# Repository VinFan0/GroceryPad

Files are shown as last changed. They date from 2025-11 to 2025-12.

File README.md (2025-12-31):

# GroceryPad
## Overview

GroceryPad is a compact display for shopping lists, to-do lists, reminders, and more. The on-board ESP32 microcontroller acts as a display driver, as well as hosts an HTTP server on the local network. Data sent to the server in the form of an HTTP POST is parsed and sent to the 3.7" Epaper module.

GroceryPad is initially designed to sync with a list managed in the Reminders app of an iOS device. In this configuration, the iOS device sends a scheduled HTTP POST with the contents of the reminder/list to the server hosted by the GroceryPad device. 

**R1.1-A changes**
- Power switch
- Android companion app for checklist display

### Hardware Requirements
- [ESP32-C3 Supermini microcontroller](https://www.espboards.dev/esp32/esp32-c3-super-mini/)
- [WeAct 3.7" Epaper module](https://github.com/WeActStudio/WeActStudio.EpaperModule)
- [HiLetgo TP4056 USB-C Lithium Battery Charging Module](https://www.amazon.com/HiLetgo-Lithium-Charging-Protection-Functions/dp/B07PKND8KG)
- [3.7V Rechargeable Lithium Polymer battery](https://www.amazon.com/dp/B0CNLPK1F8?ref=ppx_yo2ov_dt_b_fed_asin_title&th=1)
- 3mm indicator LED
- Smartphone (for automatic list syncing)

### Software Requirements
Code is uploaded to the board via ArduinoIDE, which can be downloaded here: [Download ArduinoIDE](https://www.arduino.cc/en/software/)

To connect with the ESP32 board, you must also install the ESP32 board. Instructions are available on the [espressif website](https://docs.espressif.com/projects/arduino-esp32/en/latest/installing.html)

For the automatic syncing with a smartphone list, an additional app must be used to schedule the sending of the HTTP POST. iPhones can use the Shortcuts app, which is installed by default on all devices running iOS 13 or later. For Android, I recommend [Tasker](https://play.google.com/store/apps/details?id=net.dinglisch.android.taskerm&hl=en_US). Steps for setting this up are found under the **Setup** section.

## Setup
For the GroceryPad device to function, a connection to a local WiFi network is required. Included with the Arduino sketch is a `ssid_options.h` file. This header file can be used to define the SSID and password variables the ESP32 will use to connect to WiFi. Fill in the `ssid` and `password` strings with your local WiFi details. *Note: The ESP32 is only compatible with 2.4 GHz WiFi.*

Once the `ssid_options.h` file is filled in, the code can be compiled and loaded onto the microcontroller. If the connection is successfull, the microcontroller will print a "WiFi Connected" message to the console. Along with the success message, the IP address will also be printed. Take note of this IP address, as it will be required in sending the HTTP POST messages.

### iOS Shortcuts Configuration
Setting up the Shortcut to periodically send the HTTP POST is not complicated, but can take some time to figure out if you are new to workflow automations or Apple Shortcuts specifically. Here is provided a simple walkthrough of setting up the Shortcut.

Items necessary to creating the Shortcut:
- Apple Shortcuts app is installed
- The IP address of the ESP32 HTTP server
- A Reminder list on the same iOS device

**Step 1**

**Sending messages manually** with curl

Messages can also be sent to the device manually using a linux-style terminal and the `curl` command. Basic syntax is

`curl -X POST http://<ESP IP ADDRESS>/reminder -H "Content-Type: application/json" -d '<MESSAGE CONTENT>'`

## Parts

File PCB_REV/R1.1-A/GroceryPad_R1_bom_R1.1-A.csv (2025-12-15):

Component | Description | Part | References | Value | Footprint | Quantity Per PCB | Datasheet | MFR | MPN | SPR | SPN
1 | 8 Pin Wire to Board Connector | e-ink_Display | C1 | ~ | 1.25mm_8P_WireToBoard | 1 | kicad-embed://JUSHUO_C29041.pdf | JUSHUO | 1.25T-8PWT | JLCPCB | C29041
2 | Light emitting diode | LED | D1 | LED | LED_D3.0mm_Horizontal_O6.35mm_Z2.0mm | 1 | ~ | Lumimax Optoelectronic Technology | LEDDC-3BLU | Digikey | 4491-LEDDC-3BLU-ND
3 | Resistor, US symbol | R_US | R1 | 2k | R_0805_2012Metric | 1 | kicad-embed://JLC_C1359.pdf | UNI-ROYAL(Uniroyal Elec) | 0805W8J0202T5E | JLCPCB | C1359
Component Groups: | 3
Component Count: | 3
Fitted Components: | 3
Number of PCBs: | 1
Total components: | 3
Schematic Version: | R1.1-A
Schematic Date: | 11/26/25
PCB Variant: | default
BoM Date: | 2025-12-13T23:08:35-0700
Schematic Source: | GroceryPad_R1.1-A.kicad_sch
KiCad Version: | Eeschema 9.0.6

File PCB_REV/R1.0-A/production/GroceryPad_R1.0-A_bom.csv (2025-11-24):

Designator | Footprint | Quantity | Value | LCSC Part #
R1 | R_Axial_DIN0207_L6.3mm_D2.5mm_P7.62mm_Horizontal | 1 | 2k | 0805W8J0202T5E

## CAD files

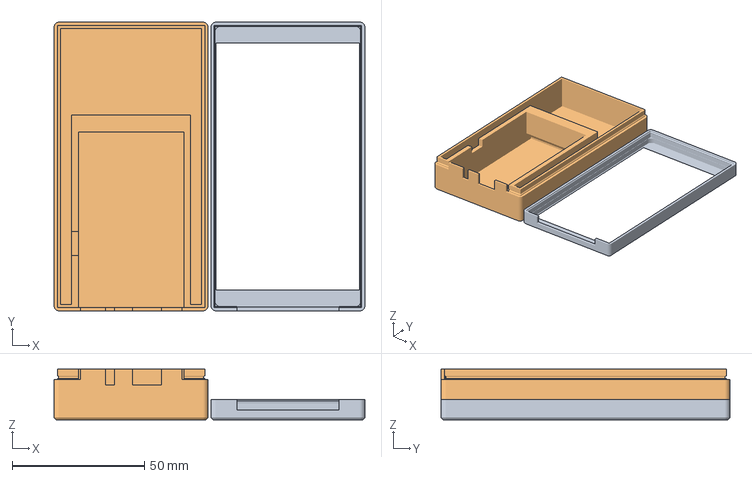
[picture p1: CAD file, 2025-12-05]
PCB_REV/R1.0-A/printing/GroceryPad.3mf
117.8 x 109.4 x 19.2 mm
Front Plate_R1.0-C.stl
Back Cover_V4.stl

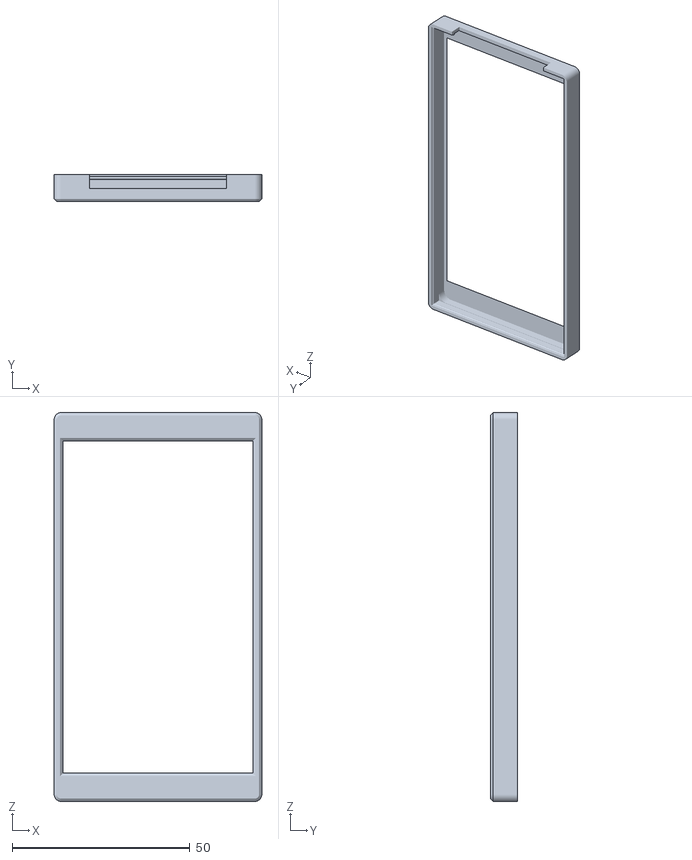
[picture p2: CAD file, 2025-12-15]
PCB_REV/R1.0-A/printing/STL/Front Plate_V4.stl
58.4 x 7.70 x 109.4

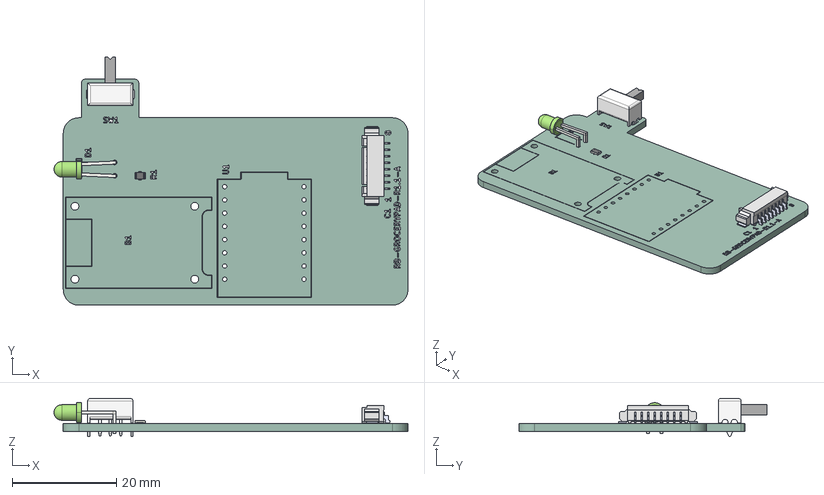
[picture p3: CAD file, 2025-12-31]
PCB_REV/R1.1-A/GroceryPad_R1.1-A.step
68.0 x 47.7 x 7.30 mm
10114830-xxxxxLF (Additional)_10114830-10108LF
LED_D3.0mm_Horizontal_O6.35mm_Z2.0mm
SK12D07VG5 Slide Switch SPDT
R_0805_2012Metric
GroceryPad_R1.1-A_silkscreen
GroceryPad_R1.1-A_PCB

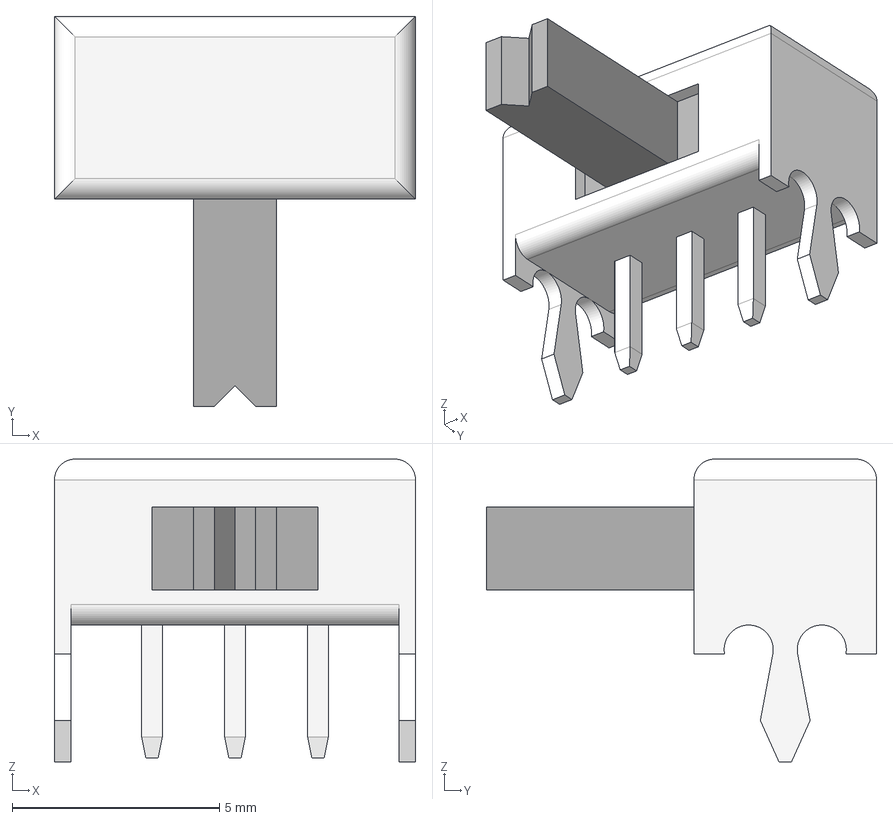
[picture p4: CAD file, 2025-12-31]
PCB_REV/R1.1-A/models/SK12D07VG5 Slide Switch SPDT.step
8.70 x 9.40 x 7.30 mm

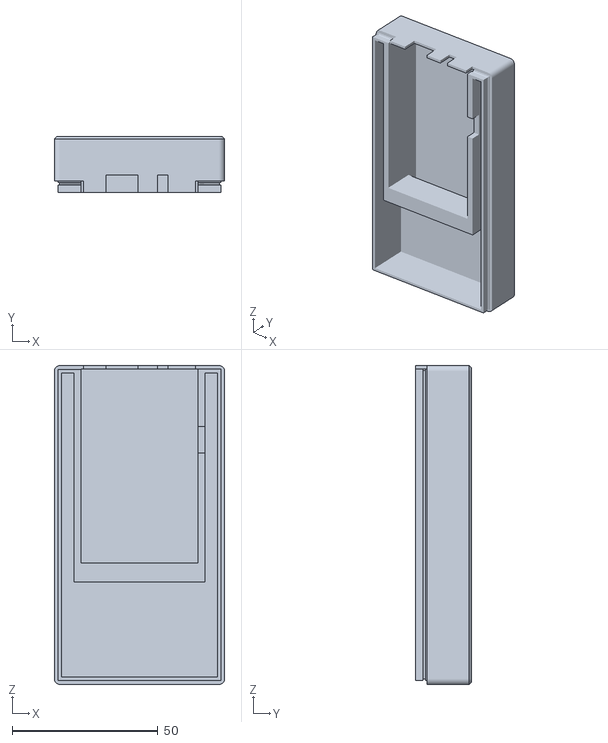
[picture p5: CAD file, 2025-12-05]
PCB_REV/R1.1-A/printing/STL/Back Cover_V4.stl
58.4 x 19.2 x 109.4

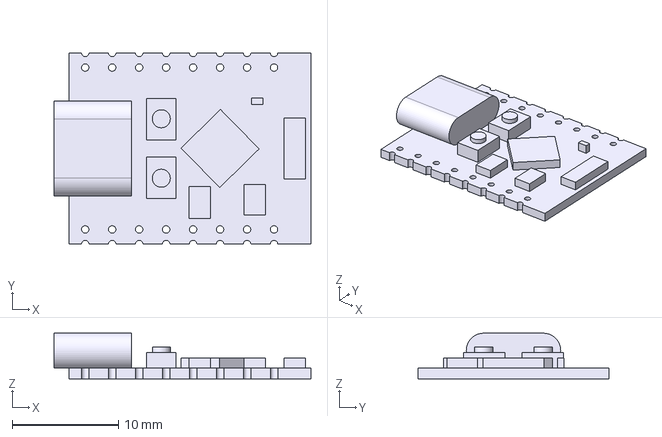
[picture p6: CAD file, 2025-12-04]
PCB_REV/R1.1-A/models/esp32c3supermini.step
24.2 x 18.0 x 4.30 mm

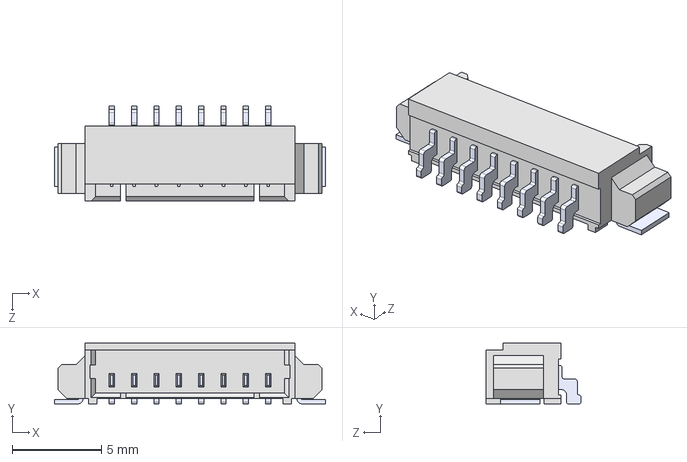
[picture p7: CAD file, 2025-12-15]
PCB_REV/R1.1-A/models/10114830-10108LF.STEP
15.2 x 3.40 x 5.30 mm

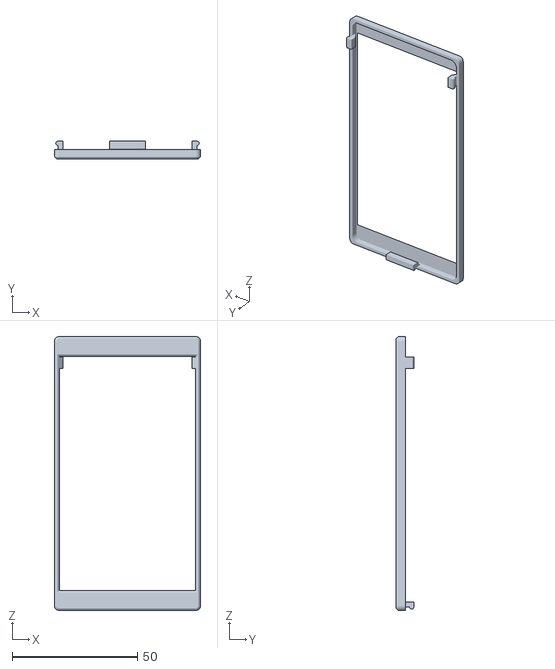
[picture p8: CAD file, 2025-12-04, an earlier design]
PCB_REV/R1.1-A/printing/STL/Front Plate_V1.stl
58.4 x 7.00 x 109.4

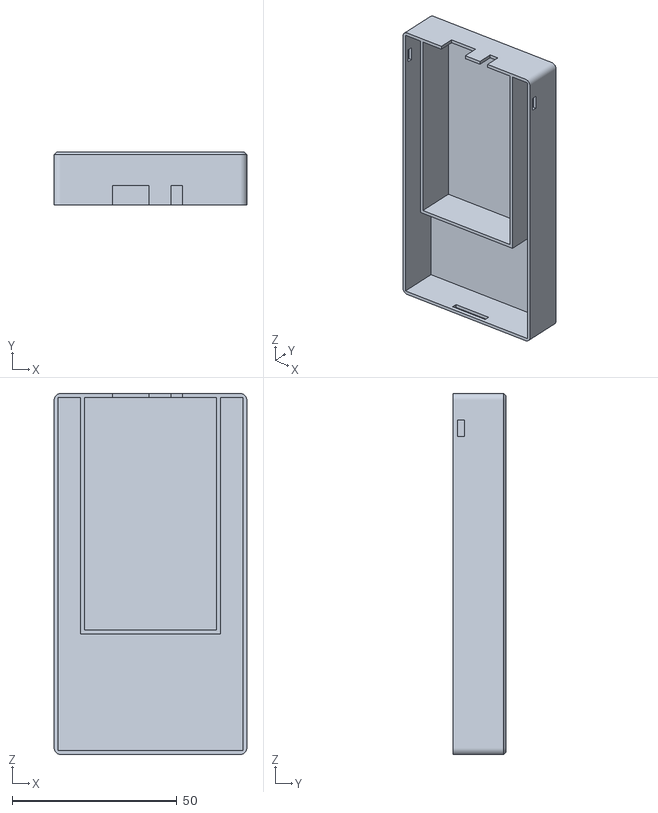
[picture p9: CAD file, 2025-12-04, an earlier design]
PCB_REV/R1.1-A/printing/STL/Back Cover_V1.stl
58.4 x 16.2 x 109.4

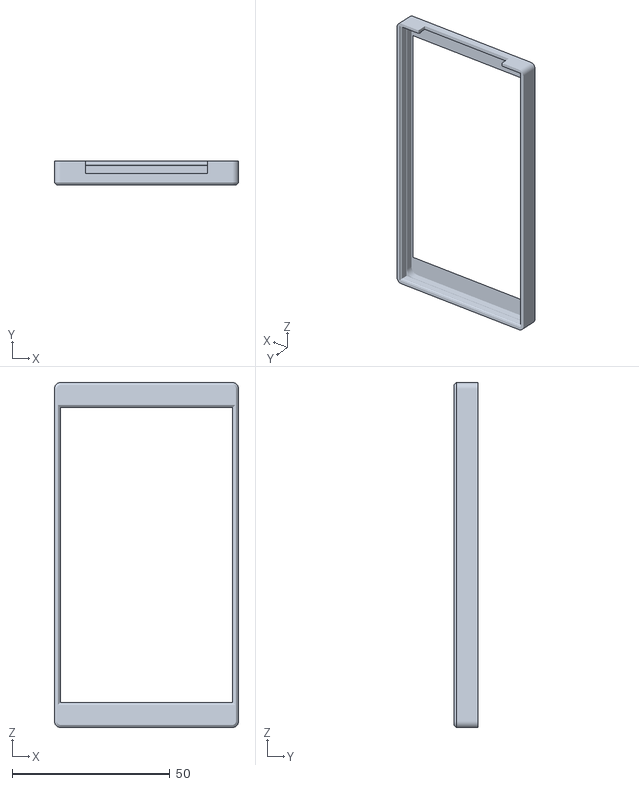
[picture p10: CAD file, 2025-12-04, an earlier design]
PCB_REV/R1.1-A/printing/STL/Front Plate_V3.stl
58.4 x 7.70 x 109.4

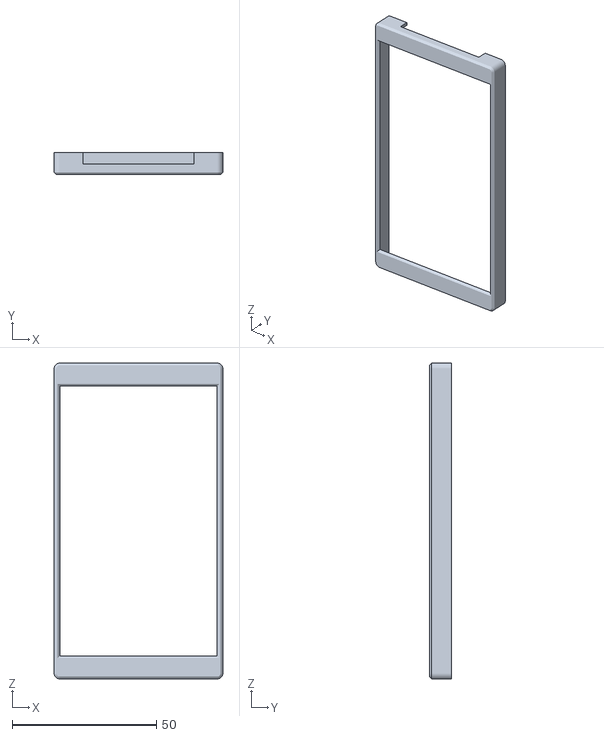
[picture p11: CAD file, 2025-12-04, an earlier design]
PCB_REV/R1.1-A/printing/STL/Front Plate_V2.stl
58.4 x 7.70 x 109.4

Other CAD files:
PCB_REV/R1.1-A/printing/GroceryPad.3mf
PCB_REV/R1.1-A/printing/STL/Back Cover_V3.stl
PCB_REV/R1.1-A/printing/STL/Back Cover_V2.stl

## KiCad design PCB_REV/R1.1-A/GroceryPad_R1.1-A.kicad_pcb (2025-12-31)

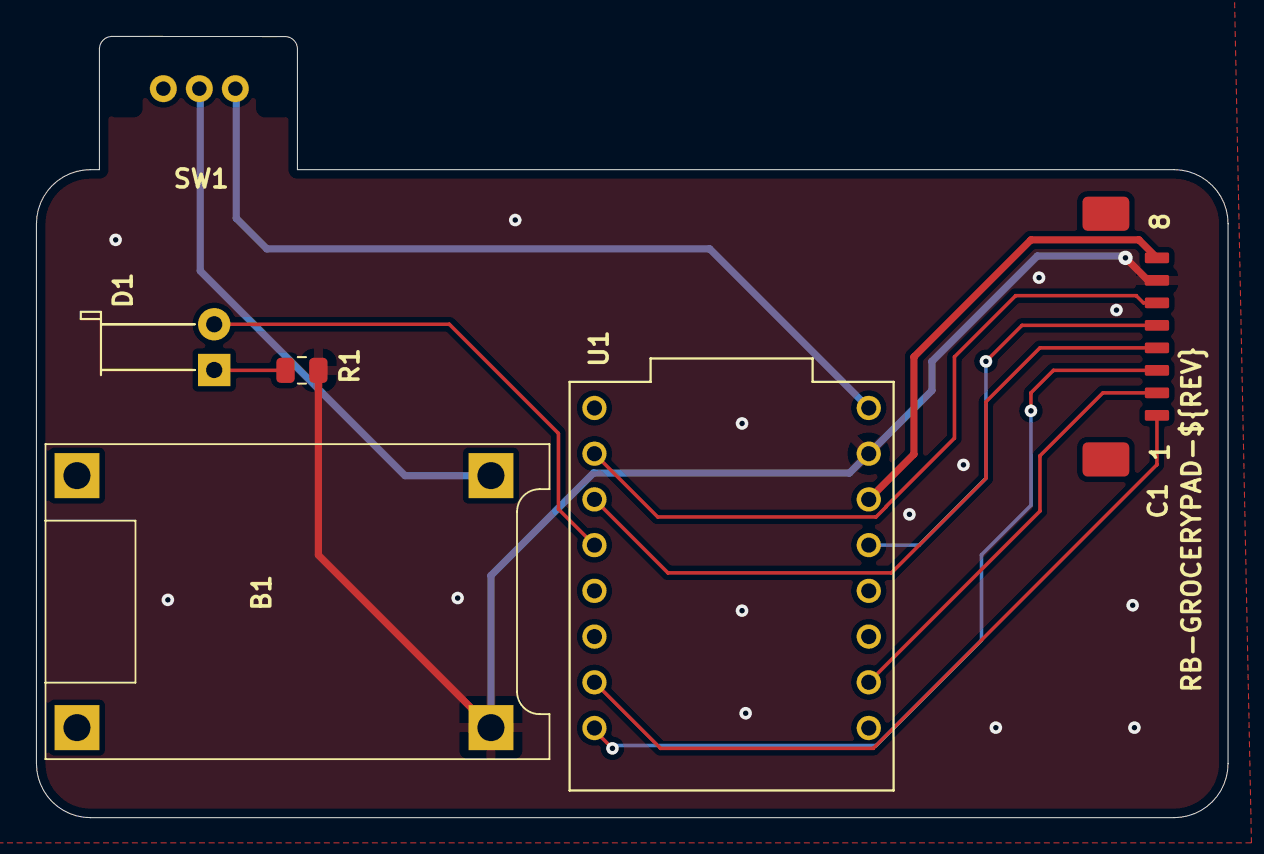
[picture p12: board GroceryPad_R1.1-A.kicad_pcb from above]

Board: 2 copper layers, 66.2 x 43.4 mm, 6 parts (0 on the bottom side), 12 nets.

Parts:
B1: HiLetgo TP4056 BOB
C1: 1.25mm_8P_WireToBoard
D1: LED; LED_D3.0mm_Horizontal_O6.35mm_Z2.0mm
R1: 2k; R_0805_2012Metric
SW1: SW_SPDT_312; SPDT Slide Switch
U1: ESP32-C3_SUPERMINI_TH; MODULE_ESP32-C3_SUPERMINI_TH

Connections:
3V3: C1.8 (VCC), U1.3.3 (3V3)
5V: B1.3 (OUT+), SW1.1 (B)
BUSY: C1.1 (BUSY), U1.20 (GPIO20)
CS: C1.4 (CS), U1.7 (GPIO7)
DC: C1.3 (DC), U1.21 (GPIO21)
GND: B1.4 (OUT-), C1.7 (GND), R1.2, U1.G (GND)
unnamed: D1.1 (K), R1.1
RES: C1.2 (RES), U1.1 (GPIO1)
SCL: C1.5 (SCL), U1.4 (GPIO4)
SDA: C1.6 (SDA), U1.6 (GPIO6)
STATUS: D1.2 (A), U1.8 (GPIO8)
SW_5V: SW1.2 (C), U1.5V

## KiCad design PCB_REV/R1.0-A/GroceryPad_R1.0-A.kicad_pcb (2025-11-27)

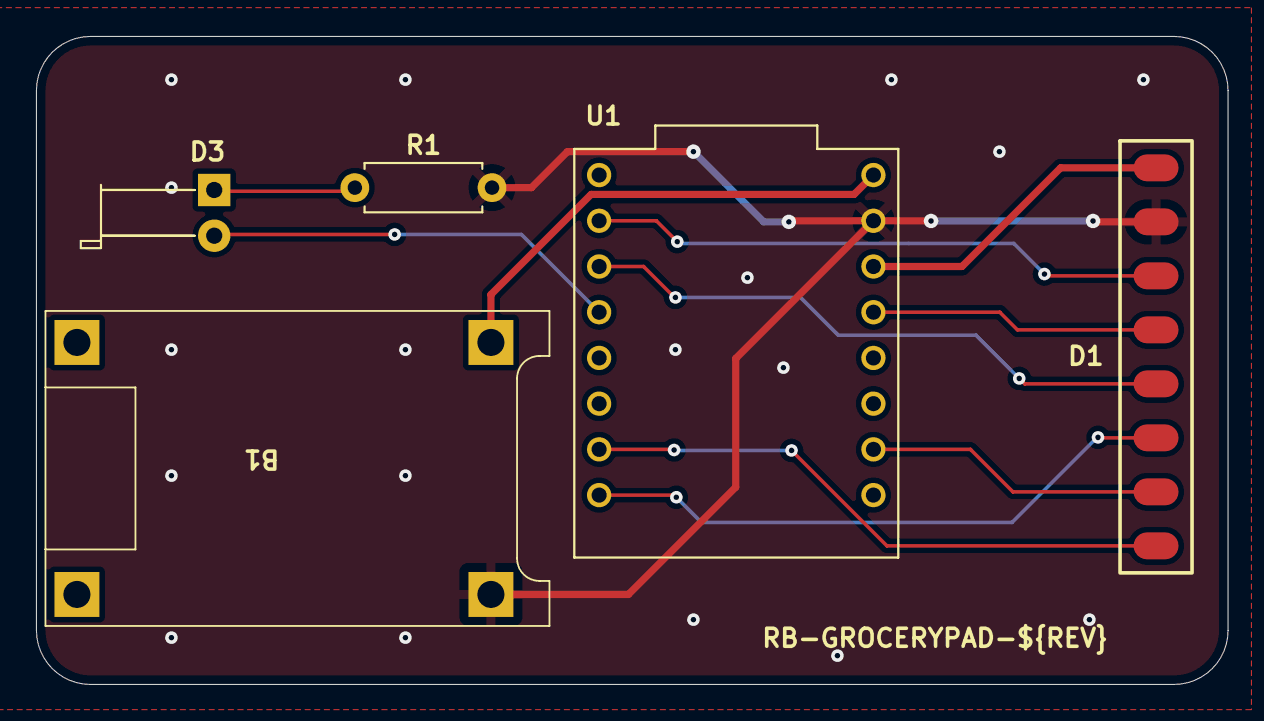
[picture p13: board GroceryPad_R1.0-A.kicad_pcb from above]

Board: 2 copper layers, 66.2 x 36.0 mm, 5 parts (0 on the bottom side), 11 nets.

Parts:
B1: HiLetgo TP4056 BOB
D1: WeAct Studio 3.7 Epaper Module
D3: LED; LED_D3.0mm_Horizontal_O6.35mm_Z2.0mm
R1: 2k; R_Axial_DIN0207_L6.3mm_D2.5mm_P7.62mm_Horizontal
U1: ESP32-C3_SUPERMINI_TH; MODULE_ESP32-C3_SUPERMINI_TH

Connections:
3V3: D1.8 (VCC), U1.3.3 (3V3)
5V: B1.3 (OUT+), U1.5V
BUSY: D1.1 (BUSY), U1.20 (GPIO20)
CS: D1.4 (CS), U1.7 (GPIO7)
DC: D1.3 (DC), U1.21 (GPIO21)
GND: B1.4 (OUT-), D1.7 (GND), R1.2, U1.G (GND)
unnamed: D3.1 (K), R1.1
RES: D1.2 (RES), U1.1 (GPIO1)
SCL: D1.5 (SCL), U1.4 (GPIO4)
SDA: D1.6 (SDA), U1.6 (GPIO6)
STATUS: D3.2 (A), U1.8 (GPIO8)

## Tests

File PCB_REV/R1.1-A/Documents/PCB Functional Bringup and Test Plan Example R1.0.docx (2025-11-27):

PCB Functional Bringup and Test Plan Example

Project Title:

Tested by:

Date:

Document revision: 1.0

Relevant proposal revision: 1.0

PCB version under test: 1.0-A

# Bringup plan

Replace/erase the red text and customize this document for your project(s)

Tools and supplies needed

- Antistatic workstation
- Magnifying glass
- Bench power supply
- Multimeter
- etc.

## Inspection plan

1. Check silkscreen for errors, overall impressions of build quality, etc.
2. Check U2, U3, etc. to make sure they are mounted correctly and are the correct component (no sneaky substitutions were made, etc.)
3. Etc.
4. Etc.

## Optional components for this test

U2, M4, etc. etc.

## Power subsystems under test

5.0v regulator, 3.3v regulator, etc.

## Other notes about bringup

Write yourself or future techs any ideas you have about bringup here

## Step-by step bringup plan

(This is where you make a plan to test EVERYTHING your PCB should do. Things like functions, environmental limits, etc. Everything that is important to you being irrelevant to this board’s future)

1. Test these circuit nodes for shorts (annotated screenshots from KiCad)
2. Partially assemble board (U4 5.0v regulator only…)
3. Partial power up and test

Test 1: Does LED1 light up? | ❒ Yes | ❒ No

Test 1 notes:

4. Install U6 power regulator, new tests

Test 2: Does U8 oscillate? | ❒ Yes | ❒ No

Test 2 notes:

5. Any changes to board

Test 3: Does U8 respond to JTAG programing? | ❒ Yes | ❒ No

Test 3 notes:

Tests 4-25 as above

# Bringup and test summary:

<A sentence or summary should go here>

# Modification summary

<If you got things to work with hand surgery, pictures of what you did and any notes about what was needed to make it work go here. Do not let any of these ideas fade away in the moment!>

# Changes needed for next revision

1. All PCB or design changes summarized with screenshots, images, etc.
2. U7 didn’t fit on the footprint
3. U4 needed to be flipped upside down
4. U19 was the wrong part number
5. Etc.

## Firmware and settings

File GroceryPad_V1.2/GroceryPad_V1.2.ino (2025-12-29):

/*
*   Project: Grocery List Display
*   Author: Ryan Beck
*
*   Board: ESP32-C3 SuperMini
*   Version: 1.2
*/

#include "epaper.h"
#include "ble_device.h"

void printList(t_displayList* list) {
  if (list->listName != "") {
    Serial.print(list->listName);
    Serial.print(" (");
    Serial.print(list->itemCount);
    Serial.println(")");
    Serial.println("*****************");
    for(int i=0; i<list->itemCount; i++) {
      if (list->listItems[i].checked) {
        Serial.print("X ");
      } else {
        Serial.print("  ");
      }
      Serial.println(list->listItems[i].itemName);
    }
  } else {
    Serial.println("Blank list");
  }
}

void setup() {
  Serial.begin(115200);
  delay(500);

  pinMode(LED_BUILTIN, OUTPUT);

  epaperInit();
  bleInit();
}

void loop() {
  if (bleConnected) {
    // BLE Connected
    digitalWrite(LED_PIN, HIGH); // Solid ON

    if (updatePending && readyToUpdate) {
      Serial.println("Received display update");
      updatePending = false;
      readyToUpdate = false;
      printList(syncedList);
      drawListItems(syncedList);
    }
  } else {
    // BLE Advertising
    digitalWrite(LED_PIN, LOW); // Short OFF
    delay(300);
    digitalWrite(LED_PIN, HIGH); // Long ON
    delay(900);

    if (!clearedOnDisconnect) {
      clearSyncedList(syncedList);
      updatePending = false;
      readyToUpdate = false;
      clearedOnDisconnect = true;
      printList(syncedList);
      drawEmptyList();
      drawListItems(syncedList);
    }
  }
}

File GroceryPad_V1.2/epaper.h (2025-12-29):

#ifndef __EPAPER_H_
#define __EPAPER_H_
/*
* EPaper.cpp
* Written by Ryan Beck
*/
// base class GxEPD2_GFX can be used to pass references or pointers to the display instance as parameter, uses ~1.2k more code
// enable or disable GxEPD2_GFX base class

#define ENABLE_GxEPD2_GFX 0

#include <GxEPD2_BW.h>
#include <Fonts/FreeMonoBold9pt7b.h>

/* ESP32-C3 SuperMini
        CS(SS)=7
        SCL(SCK)=4
        SDA(MOSI)=6
        BUSY=20
        RES(RST)=1
        DC=21
*/
#define CS_PIN (7)
#define BUSY_PIN (20)
#define RES_PIN (1)
#define DC_PIN (21)

// 3.7'' EPD Module
GxEPD2_BW<GxEPD2_370_GDEY037T03, GxEPD2_370_GDEY037T03::HEIGHT> display(GxEPD2_370_GDEY037T03(
                                                                            /*CS=7*/ CS_PIN, 
                                                                            /*DC=21*/ DC_PIN, 
                                                                            /*RES=1*/ RES_PIN, 
                                                                            /*BUSY=20*/ BUSY_PIN)); // GDEY037T03 240x416, UC8253

#define START_LINE 25       // First page line
#define LINE_OFFSET 25      // Page line spacing
#define START_ITEM 45       // First item Y cursor
#define ITEM_X 18           // Item X cursor

#define TITLE_Y 15          // Title Y cursor

#define BLOCK_X 16          // Partial block X position
#define DISPLAY_WIDTH 240   // Partial block width (end of display)
#define BLOCK_H 23          // Partial block height

struct t_listItem{
  String itemName;
  bool checked;
};

struct t_displayList{
  String listName = "";
  int itemCount = 0;
  std::vector<t_listItem> listItems;
};

t_displayList *syncedList = new t_displayList();

void drawEmptyList() {
  display.firstPage();
  do
  {
    // Clear full screen
    display.fillScreen(GxEPD_WHITE);

    // Draw Page Header Lines
    display.fillRect(0, 22, 240, 3, GxEPD_BLACK); // Bold line
    display.drawLine(10, 0, 10, 416, GxEPD_BLACK); // Vertical line
    
    // Draw Page Lines
    for (int i=0; i<16; i++) {
      display.drawLine(0, START_LINE+LINE_OFFSET*i, 240, START_LINE+LINE_OFFSET*i, GxEPD_BLACK);
    }
  }
  while (display.nextPage());
}

void drawListItems(t_displayList *list) {

  display.setPartialWindow(BLOCK_X, 0, DISPLAY_WIDTH, 20);  // Title block window

  // List Name
  display.firstPage();
  do
  {
    display.fillRect(BLOCK_X, 0, DISPLAY_WIDTH, 20, GxEPD_WHITE);

    display.setCursor(BLOCK_X, TITLE_Y);
    if (list->listName != "") {
      display.print(list->listName);
    } else {
      display.print("No List");
    }
  } 
  while (display.nextPage());
  
  // List Items
  if (list->itemCount != 0) {
    int displayCount = 0;
    if (list->itemCount > 15) {
      displayCount = 15;
    } else {
      displayCount = list->itemCount;
    }
    
    for (int i=0; i<displayCount; i++) {
      display.setPartialWindow(BLOCK_X, START_LINE + 2 + i*LINE_OFFSET, DISPLAY_WIDTH, BLOCK_H);

      display.firstPage();
      do
      {
        display.fillRect(BLOCK_X, START_LINE + 1 + i*LINE_OFFSET, DISPLAY_WIDTH, BLOCK_H, GxEPD_WHITE);

        // display.setCursor(ITEM_X, START_ITEM + i*LINE_OFFSET);
        display.setCursor(BLOCK_X, START_LINE + 18 + i*LINE_OFFSET);
        display.print(list->listItems[i].itemName);
        if(list->listItems[i].checked) {
          display.fillRect(BLOCK_X, START_LINE + 12 + i*LINE_OFFSET , 12*list->listItems[i].itemName.length(), 2, GxEPD_BLACK);
        }
      }
      while(display.nextPage());
    }
  } else {
    // display.setPartialWindow(BLOCK_X, START_ITEM, DISPLAY_WIDTH, BLOCK_H);
    // display.firstPage();
    // do{
    //   display.setCursor(BLOCK_X, START_ITEM);
    //   display.print("No items");
    // }
    // while(display.nextPage());
  }
}

void clearSyncedList(t_displayList *list) {
  list->listName = "";
  list->itemCount = 0;
  list->listItems.clear();
}

void epaperInit() {
  // E-Paper Display
  display.init(115200,true,50,false);
  display.setRotation(2);
  display.setFont(&FreeMonoBold9pt7b);
  display.setTextColor(GxEPD_BLACK);
  display.setFullWindow();

  // Draw page outline
  drawEmptyList();
  Serial.println("Display ready");  
}
#endif //__EPAPER_H_

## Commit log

2025-11-23 Configured for ESP32-C3 device
2025-11-23 Working with battery power
2025-11-24 PCB R1.0-A
    [GroceryPad_R1.0-A.kicad_pcb, GroceryPad_R1.0-A.kicad_sch, GroceryPad_R1.0-A_bom.csv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]
2025-11-27 TP4056 breakout footprint
    [GroceryPad_R1.0-A.kicad_pcb, GroceryPad_R1.0-A.kicad_sch]
2025-11-27 R1.0- A sent to production
    [GroceryPad_R1.0-A_positions.csv]
2025-12-04 R1.0-A final
    [Back Cover_R1.0-A.stl, Back Cover_R1.0-B.stl, Back Cover_R1.0-C.stl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]
2025-12-05 Remove Arduino directory and README update
2025-12-05 Printing files with foam spacer
    [Back Cover_V1.stl, Back Cover_V2.stl, Back Cover_V3.stl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]
2025-12-15 Arduino sketch version 1.0 and 1.1
    [10114830-10108LF.STEP, Back Cover_V1.stl, Back Cover_V2.stl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]
2025-12-31 Power switch and case update
    [GroceryPad_R1.1-A.kicad_pcb, GroceryPad_R1.1-A.kicad_sch, GroceryPad_R1.1-A.step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]
